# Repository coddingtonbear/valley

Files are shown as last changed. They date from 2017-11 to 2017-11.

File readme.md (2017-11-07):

# Whiterose: A DIY Rescuetime + ESP32 Productivity Monitor IOT Device

Whiterose Boot (http://www.youtube.com/watch?v=nXMo9l9A4Xc "Whiterose IOT Boot")

Whiterose is a DIY project you can use for building a (relatively) simple device for giving you an up-to-date assessment of how productive (or distracted) you are.

## Parts List (BOM)

* 1x ESP32 ([~$4 on AliExpress](https://www.aliexpress.com/item/ESP-WROOM-32-ESP32-Bluetooth-and-WIFI-Dual-Core-CPU-with-Low-Power-Consumption-MCU/32793415575.html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,searchweb201602_4_10152_10065_10151_10130_10068_10344_10345_10547_10342_10546_10343_10340_10341_10548_10545_10541_10307_10060_10155_10154_10056_10055_10539_10537_10536_10059_10534_10533_100031_10103_10102_5670015_10142_10107_10324_5660015_10325_10562_10084_10083_10561_10178_10312_10313_10314_5650015_10550_10073_10551_10552_10553_10554_10557_10558-10552,searchweb201603_2,ppcSwitch_5&btsid=a117c8df-c8ed-4f43-8924-000555686ad1&algo_expid=a394fe7b-2047-489e-8816-9dba91acb8ad-3&algo_pvid=a394fe7b-2047-489e-8816-9dba91acb8ad))
* 1x CH341A USB->UART ([~$1 on AliExpress](https://www.aliexpress.com/item/Free-shipping-CH341A-SOP28-USB-bus-switching-chip/32465435558.html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,searchweb201602_4_10152_10065_10151_10130_10068_10344_10345_10547_10342_10546_10343_10340_10341_10548_10545_10541_10307_10060_10155_10154_10056_10055_10539_10537_10536_10059_10534_10533_100031_10103_10102_5670015_10142_10107_10324_5660015_10325_10562_10084_10083_10561_10178_10312_10313_10314_5650015_10550_10073_10551_10552_10553_10554_10557_10558-10552,searchweb201603_2,ppcSwitch_5&btsid=278ad066-3504-4684-8782-9417db61a984&algo_expid=eaf47891-7115-42b5-9a58-e7a70337a5e1-37&algo_pvid=eaf47891-7115-42b5-9a58-e7a70337a5e1))
* 1x 1.8inch TFT LCD Module using ST7735R ([~5 on AliExpress](https://www.aliexpress.com/item/1-8-inch-TFT-LCD-Display-Module-with-PCB-Board-ST7735R-Drive-IC-SPI-Serial-Interface/32350099643.html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))
* 1x SLV6A RGB LED
* 1x UJ2-MIBH-4 USB Connector
* 1x AP1117-3.3v Voltage Regulator
* 1x HC49 12MHz SMD Crystal
* Miscellaneous passives
    * 2x 10Ω 0805 SMD Resistor (for blue/green LEDs)
    * 1x 150Ω 0805 SMD Resistor (for red LED)
    * 2x 10kΩ 0805 SMD Resistor (pull-ups)
    * 2x 22pF 0805 SMD Capacitor (for crystal -- may need adjustment depending upon your technique, see errata!)
    * 1x 0.1uF 0805 SMD Capacitor (for decoupling the CH341A)
    * 1x 220mF F-Size SMD Capacitor

## 3d Printing (STL Files)

See the `3d` folder of the project.

## Actual Photos

Fully-encosed
Uncovered
PCB Front
PCB Back

## Schematic

Schematic

## Errata

The following are problems I encountered while making this board.  All have been corrected on the included schematics, but you may see my workarounds for these problems in the board photos above:

* If you look closely at photos of the board, you might notice that there was originally an SOT-23 package between the 3V3 line, a pin of the microcontroller, and the LCD panel's backlight control pin.  That device was a BSS138 transistor.  I had originally intended the LCD backlight to be controllable by the microcontroller, but hadn't considered the voltage drop across the transistor, and that voltage drop was sufficient enough when powered by a 3.3V power source for the backlight to no longer be able to turn on (if you look carefully at the photo, you might notice a tiny copper wire bridging two pins of the transistor).  In an earlier version of this board, I had used a different microcontroller that used a 5V power source instead of a 3.3V power source, so the voltage drop was accidentally not enough to prevent the backlight from lighting.  Not a huge deal, though, luckily.
* You may also notice that I don't have any capacitors between my crystal and ground.  This was definitely not something I was expecting, but it does seem like milled boards have higher intrinsic capacitance than boards that are etched otherwise.  You may actually need to populate SMD capacitors there -- I have in all other boards that I didn't mill.  22pF is a commonly-recommended value.
* You might notice a weird unsoldered via on the RTS line.  That was an accident!  I think I double-pressed `v` when routing that trace in KiCad and somehow didn't notice.

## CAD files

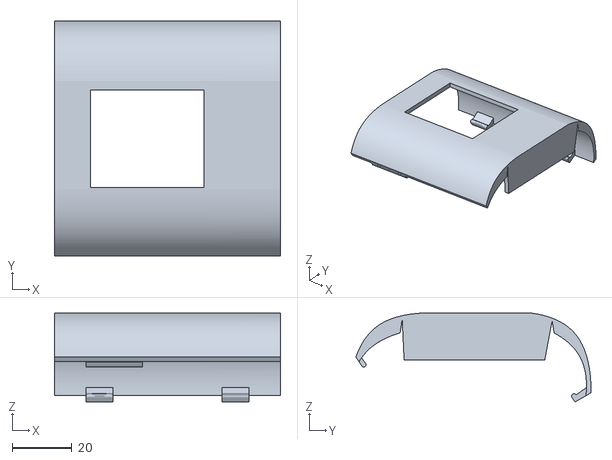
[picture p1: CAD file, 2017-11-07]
3d/whiterose_front.stl
75.5 x 78.6 x 29.7

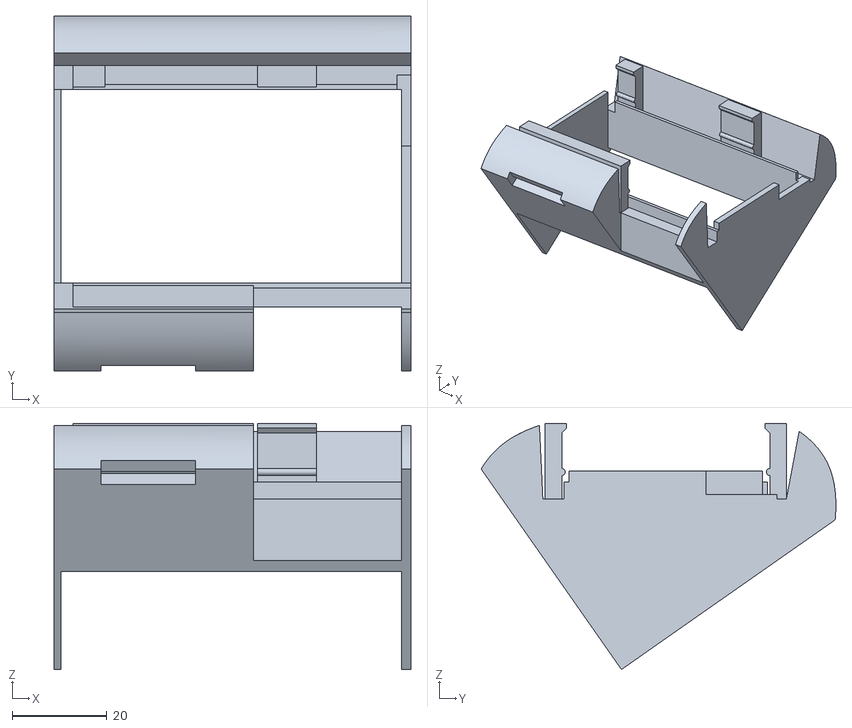
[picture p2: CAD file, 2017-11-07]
3d/whiterose_base.stl
75.5 x 75.0 x 52.0

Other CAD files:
3d/Whiterose Enclosure v15.f3d
enclosure/Valley Enclosure v12.f3d

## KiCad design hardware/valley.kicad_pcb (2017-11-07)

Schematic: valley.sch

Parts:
C1, C2: 22p; 0805_Milling
C3: 0.1u; 0805_Milling
C12: 1000u; CAP-SMD-SIZE-F
D1: LED_RGB; SLV6A-FKB-MILLING
P2: USB_OTG; UJ2-MIBH-4-SMT
P4: CONN_01X16; Pin_Header_Straight_1x16_Pitch2.54mm
R1, R4: 10; 0805_Milling
R3, R7: 10k; 0805_Milling
R5: 150; 0805_Milling
U1: CH341A; SOIC-28W_7.5x17.9mm_Pitch1.27mm
U2: AP111733; SOT-223
U3: ESP32-WROOM
Y1: 12M; Crystal_SMD_HC49-SD_HandSoldering

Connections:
+3V3: C3.1, C12.1, P4.2, P4.15, R3.2, R7.1, U1.9, U1.28, U2.2, U2.4, U3.2
+5V: P2.1 (VBUS), U2.3
A0: P4.10, U3.11
CS_SD: P4.3, U3.26
CS_TFT: P4.7, U3.9
DTR: R7.2, U1.20, U3.25
GND: C1.1, C2.1, C3.2, C12.2, D1.1, D1.2, D1.3, P2.5 (GND), P2.6 (shield), P4.1, P4.16, U1.12, U1.27, U2.1, U3.1, U3.15, U3.38, U3.39
LED_BLUE: R1.2, U3.31
LED_GREEN: R4.2, U3.30
LED_RED: R5.2, U3.29
MISO: P4.5, U3.14
MOSI: P4.4, P4.9, U3.16
unnamed: C1.2, U1.13, Y1.1
unnamed: C2.2, U1.14, Y1.2
unnamed: D1.4, R1.1
unnamed: D1.5, R4.1
unnamed: D1.6, R5.1
RESET_TFT: P4.11, U3.10
RTS: R3.1, U1.21, U3.3
RXD: U1.5, U3.34
SCK: P4.6, P4.8, U3.13
TXD: U1.6, U3.35
UD+: P2.3 (D+), U1.10
UD-: P2.2 (D-), U1.11
USB_CONNECTED: U1.1, U3.33

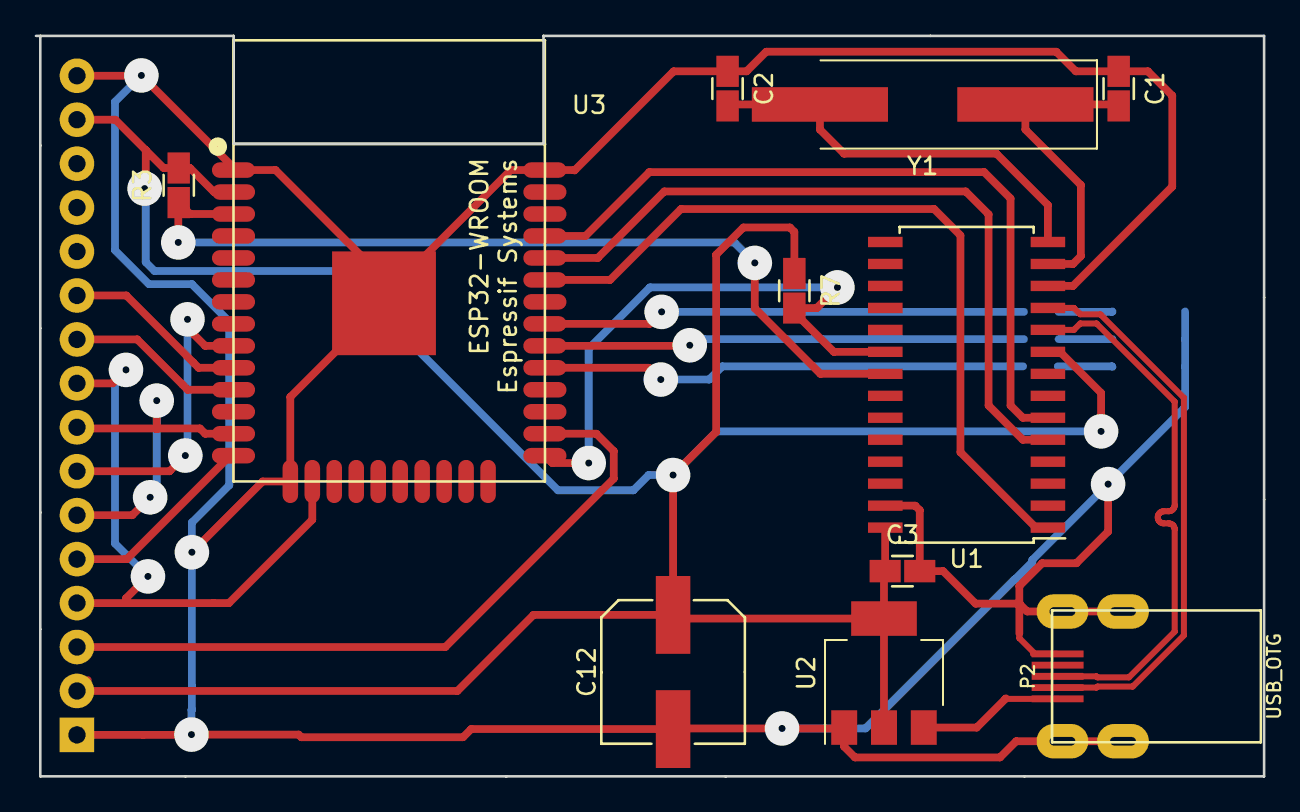
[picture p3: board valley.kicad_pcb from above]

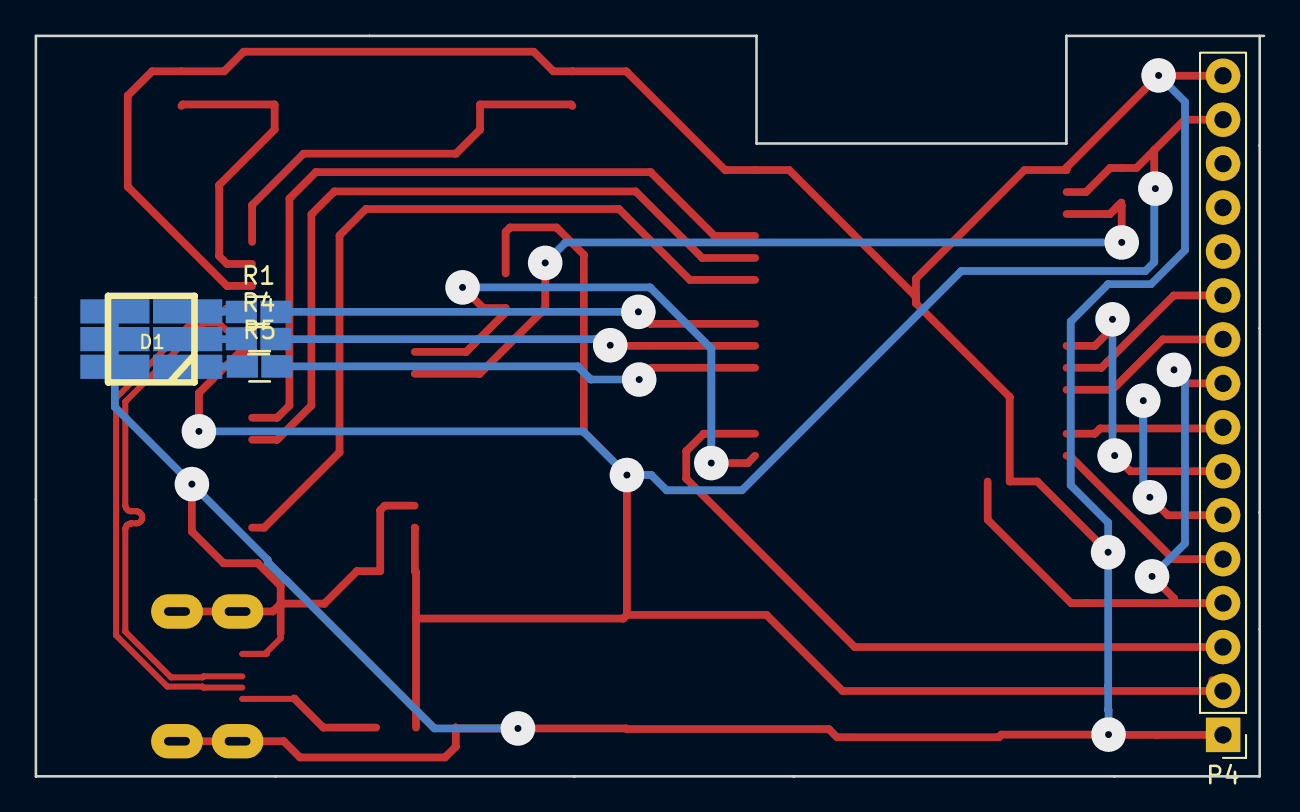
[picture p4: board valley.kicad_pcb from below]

Board: 2 copper layers, 71.0 x 42.8 mm, 16 parts (5 on the bottom side), 25 nets.

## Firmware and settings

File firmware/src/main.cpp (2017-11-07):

#include "main.h"

SPIClass hspi;
Display display;
RescueTime rescuetime = RescueTime(String(RESCUETIME_API_KEY));

bool connected = false;
unsigned long lastSample = 0;
unsigned long lastRefresh = 0;

float lastProductivityScoreDisplayed = -1;
float productivityScoreDisplayed = -1;
int productivityScore = 0;

WiFiMulti wifi;


void setup()
{
    Serial.begin(115200);

    hspi = SPIClass(HSPI);
    hspi.begin(14, 12, 13);

    pinMode(SD_CS, OUTPUT);

    digitalWrite(LED_R, 0);
    digitalWrite(LED_G, 0);
    digitalWrite(LED_B, 0);

    display = Display(
        &hspi, LCD_CS, LCD_DC, LCD_RST,
        LED_R, LED_G, LED_B
    );
    display.setup();
    display.fillScreen(0, 0, 30);
    display.setLedColor(0, 0, 100, EFFECT_BREATHE);

    xTaskCreatePinnedToCore(
        backgroundLoop,
        "backgroundLoop",
        4092,
        NULL,
        1,
        NULL,
        0
    );

    for (
        uint8_t i = 0;
        i < (sizeof(wifiPasscodes)/sizeof(wifiPasscode));
        i++
    ) {
        wifi.addAP(wifiPasscodes[i].ssid, wifiPasscodes[i].pwd);
    }

    Serial.print("Connecting to wifi...");
    long started = millis();
    display.setText("Connecting to wifi...");
    while(wifi.run() != WL_CONNECTED) {
        if (millis() > started + WIFI_FAILURE_RESTART) {
            display.fillScreen(255, 0, 0);
            display.setTextColor(255, 255, 255);
            display.setBigText("W" + String(wifi.run()));
            delay(5000);
            ESP.restart();
        }
    }
    display.fillScreen(0, 0, 0);
    display.setText("Connected as \n'" + WiFi.localIP().toString() + "'");
    Serial.println();
    Serial.println("Connected as " + WiFi.localIP().toString());
    delay(3000);
}

void backgroundLoop(void* pvParameters) {
    while(true) {
        display.loop();
        delay(10);
    }
}

void loop()
{
    if(digitalRead(NOT_USB_ENUMERATED)) {
        display.setLedColor(0, 0, 10, EFFECT_BREATHE);
        display.fillScreen(0, 0, 0);
        return;
    }

    if(lastSample == 0 || (millis() - lastSample > SAMPLE_INTERVAL)) {
        float productivityScoreResult = rescuetime.getProductivityScore();
        Serial.print("Current Productivity: ");
        Serial.println(productivityScore);
        if(productivityScoreResult >= 0) {
            productivityScore = productivityScoreResult;
            lastSample = millis();
        } else if(productivityScoreResult != -3) {
            display.fillScreen(255, 0, 0);
            display.setTextColor(255, 255, 255);
            display.setBigText("E" + String(abs(productivityScoreResult)));
            delay(5000);
            productivityScoreDisplayed = -1;
        }
    }

    if(productivityScore != productivityScoreDisplayed) {
        lastProductivityScoreDisplayed = productivityScoreDisplayed;
        productivityScoreDisplayed = productivityScore;

        int roundedProductivityScore = (int)round(productivityScore);

        colorContainer textColor = getTextColorForProductivityScore(
            roundedProductivityScore
        );
        colorContainer bgColor = getBackgroundColorForProductivityScore(
            roundedProductivityScore
        );

        display.fillScreen(bgColor.r, bgColor.g, bgColor.b);
        display.setTextColor(textColor.r, textColor.g, textColor.b);
        Serial.print("BGColor: #");
        Serial.print(bgColor.r, HEX);
        Serial.print(bgColor.g, HEX);
        Serial.println(bgColor.b, HEX);
        Serial.print("TxtColor: #");
        Serial.print(textColor.r, HEX);
        Serial.print(textColor.g, HEX);
        Serial.println(textColor.b, HEX);

        if(productivityScore < 100) {
            display.setBigText(String(roundedProductivityScore));
        } else {
            display.setBigText("OK");
        }

        if(lastProductivityScoreDisplayed >= 0) {
            if(lastProductivityScoreDisplayed > productivityScoreDisplayed) {
                display.setLedColor(20, 10, 0, EFFECT_BREATHE);
            } else if (lastProductivityScoreDisplayed == productivityScoreDisplayed) {
                display.setLedColor(10, 10, 10, EFFECT_BREATHE);
            } else {
                display.setLedColor(0, 20, 10, EFFECT_BREATHE);
            }
        } else {
            display.setLedColor(10, 10, 10, EFFECT_BREATHE);
        }

    }
}


colorContainer getTextColorForProductivityScore(int score) {
    colorContainer color;

    if (score >= 50) {
        color.r = 0;
        color.g = 0;
        color.b = 0;
    } else {
        color = display.calculateIntermediate(
            200, 0, 0,
            0, 0, 0,
            (float)(_max(score - 25, 0)) / 25
        );
    }

    return color;
}

colorContainer getBackgroundColorForProductivityScore(int score) {
    colorContainer color;

    if (score >= 50) {
        color = display.calculateIntermediate(
            200, 0, 0,
            0, 200, 0,
            (float)(_max(score - 50, 0)) / 50
        );
    } else {
        color = display.calculateIntermediate(
            0, 0, 0,
            200, 0, 0,
            (float)score/50
        );
    }

    return color;
}

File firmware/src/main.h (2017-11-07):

#define ARDUINOJSON_DEFAULT_NESTING_LIMIT 25

#include <Arduino.h>
#include <ArduinoJson.h>
#include <SPI.h>
#include <WiFi.h>
#include <WiFiMulti.h>
#include <Esp.h>

#include "rescuetime.h"
#include "configuration.h"
#include "display.h"
#include "rescuetime.h"

#define LED_R 5
#define LED_G 18
#define LED_B 19

#define LCD_CS 33
#define LCD_RST 25
#define LCD_DC 26

#define SD_CS 4

#define NOT_USB_ENUMERATED 21

#define SAMPLE_INTERVAL 60000

#define WIFI_FAILURE_RESTART 30000

void setup();
void backgroundLoop(void* pvParameters);
void loop();

colorContainer getTextColorForProductivityScore(int);
colorContainer getBackgroundColorForProductivityScore(int);

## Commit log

2017-04-10 And so it begins...
    [valley.kicad_pcb, valley.sch]
2017-04-10 Moving LED to back of board.
    [valley.kicad_pcb, valley.sch]
2017-04-11 Updating schematic to link SDA/MOSI and SCL/SCK.
    [valley.kicad_pcb, valley.sch]
2017-04-15 Removing some unnecessary pullup resistors.
    [valley.kicad_pcb, valley.sch]
2017-04-17 Updating schematics for wider trace width; 15mil is enough.
    [valley.kicad_pcb, valley.sch]
2017-04-24 Updating schematic for v 1.1.
    [valley.kicad_pcb, valley.sch]
2017-06-19 Adding final enclosure design.
    [Valley Enclosure v12.f3d]
2017-06-19 Adding latest schematic.
    [valley.sch]
2017-06-25 Fully-working, now.
    [configuration.h]
2017-06-29 Switching to a Eurostile-y font.
2017-06-30 Adding LED throbbing support; adding Michroma font.
2017-10-07 Updating to latest kicad version before next iteration.
    [valley.sch]
2017-10-08 ESP12E version laid out.
    [valley.kicad_pcb, valley.sch]
2017-10-08 Removing top copper nonsignal layer.
    [valley.kicad_pcb]
2017-10-09 I just realized that I don't need a ground plane -- with milling, I get a copper layer for free.
    [valley.kicad_pcb]
2017-10-27 Updating to use ESP32 as main processor -- no need of the separate LED driver or I2C IO expander.
    [valley.kicad_pcb, valley.sch]
2017-10-28 Swapping CH340G to CH341A
    [valley.kicad_pcb, valley.sch]
2017-10-28 Setting reference point.
    [valley.kicad_pcb]
2017-10-29 Swapping ATMEGA1284 for an ESP32 -- no driver necessary now.
    [display.cpp, display.h, main.cpp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]
2017-10-29 Adding configuration variables for wifi ssid/pwd.
    [configuration.h]
2017-10-30 Pulse the LED to indicate direction of productivity change.
2017-10-30 Make the LED slightly less bright.
2017-11-03 Calculate max color values by using LEDC_TIMER_BIT rather than having hard-coded values.
2017-11-03 Distinguish between HTTP errors and connection errors; do not emit error message for the latter.
    [main.cpp, rescuetime.cpp]
2017-11-04 Minor changes to LED colors.
2017-11-07 Updating to allow multiple WiFi AP passwords.
    [configuration.h]
2017-11-07 Run LED breathing l oop on the other core.
2017-11-07 Minor changes to LED colors and effects.
2017-11-07 Minor schematic updates.
    [valley.kicad_pcb, valley.sch]
2017-11-07 Updating readme; adding 3d files, etc.
    [Whiterose Enclosure v15.f3d, whiterose_base.stl, whiterose_front.stl]
